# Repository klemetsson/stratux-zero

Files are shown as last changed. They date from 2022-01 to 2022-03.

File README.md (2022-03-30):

# Stratux Zero

Portable ADS-B/Flarm/OGN traffic receiver, AHRS, GNSS, pressure altitude and CO-alarm based on the Stratux project and a Raspberry Pi Zero 2.

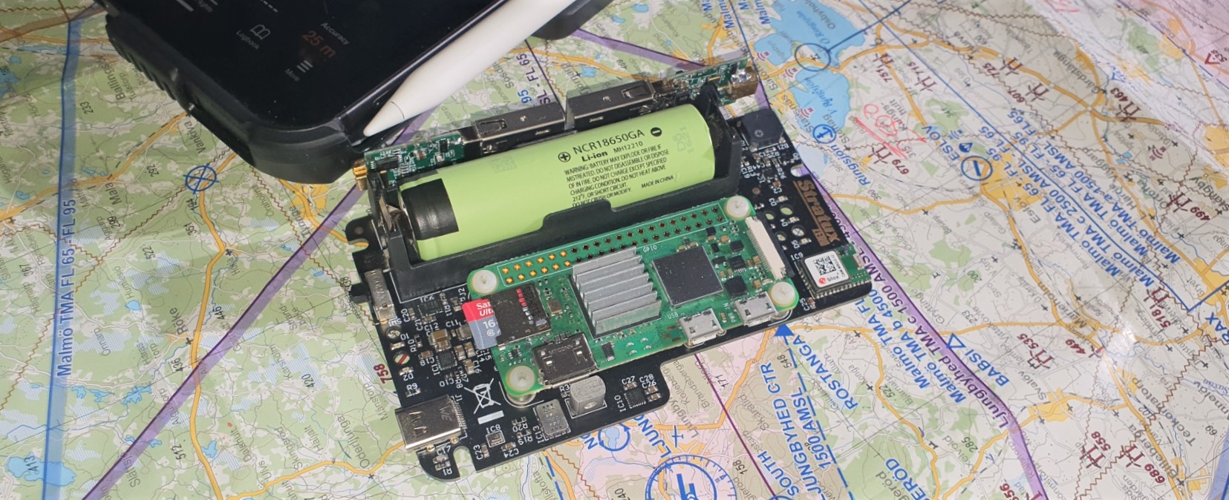
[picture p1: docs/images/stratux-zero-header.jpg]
Stratux Zero


The Flarm/OGN can be reconfigured for 978 MHz UAT for non-European use.

This project is based on the great work of:
- [Stratux (cyoung/stratux)](https://github.com/cyoung/stratux)
- [Stratux - European edition (b3nn0/stratux)](https://github.com/b3nn0/stratux)

The Stratux software for this project is mostly untouched. The main addition is
a more user friendly build system with more configuration and customization
options. It also has the firewall enabled and does more cleanup and tweaking to
enable faster boot time and lower power consumption.

Read more about the Stratux project at [stratux.me](http://stratux.me/) and at [dross:aviation](https://dross.net/aviation/).

> Note that this **does not** replace any primary systems and should only be used as a complement for cross-reference and data collection for post-flight debrief.
> None of the software or hardware has been tested or certified by any independent agent and should not be relied upon.
>
> THE SOFTWARE IS PROVIDED “AS IS”, WITHOUT WARRANTY OF ANY KIND, EXPRESS OR IMPLIED, INCLUDING BUT NOT LIMITED TO THE WARRANTIES OF MERCHANTABILITY, FITNESS FOR A PARTICULAR PURPOSE AND NONINFRINGEMENT.

## Features

- Dual USB 2.0 receptacles for [NooElec NESDR Nano 2+](https://www.nooelec.com/store/nesdr-nano2.html) or similar, [Microchip USB2512](https://www.microchip.com/en-us/product/USB2512)
- Pressure altimeter, [Bosch BMP280](https://www.bosch-sensortec.com/products/environmental-sensors/pressure-sensors/bmp280/)
- 9-axis motion tracking with 3x gyroscopes, 3x accelerometers and 3x compasses, [TDK ICM-20948](https://invensense.tdk.com/products/motion-tracking/9-axis/icm-20948/)
- GNSS (GPS, Galileo, GLONASS, BeiDou) with 2.5 m CEP accuracy, support for GAGAN, WAAS, EGNOS and MSAS augmentation, **does not** support RAIM, [u-blox CAM-M8Q](https://www.u-blox.com/en/product/cam-m8-series)
- GNSS backup power for faster initial lock
- Carbon monoxide detector with 85 dB audible alarm, [SGX MICS-4514](https://sgx.cdistore.com/products/detail/mics4514-sgx-sensortech/333417/)
- Battery socket that take standard 18650 battery without built-in protection
- 4.2 V overvoltage, 2.5 V undervoltage and over-current protection, **make sure to select a battery that is compatible**, [TI BQ2972](https://www.ti.com/product/BQ2972)
- USB C power with built-in 1 A charger (can be set up to 3.15 A with a resistor change), with support for USB BC1.2, USB Type-C Rev. 1.2 CC, Apple, Samsung and legacy USB charge adapters, [Maxim MAX77751](https://www.maximintegrated.com/en/products/power/battery-management/MAX77751.html)
- Can be powered from 4.5 to 13.7 V DC with a connector adapter with a detection resistor
- High and low battery temperature monitoring with charging inhibitor
- Fuel gauge that monitors the battery state of charge and aging, [TI BQ27441](https://www.ti.com/product/BQ27441-G1)
- Hard/soft power switch that first signals the Raspberry to shutdown cleanly and if that takes to long, power will be cut
- Optimized for a Raspberry Pi Zero 2
- Reduced Wifi transmit power to limit the range at which the open access point is visible
- Watchdog that resets the Raspberry Pi if it become unresponsive
- System boots in about 11 seconds
- Five LED indicators
    - Green power indicator that flashes every 5 seconds if low battery and 2 times per second if very low
    - Green Stratux status indicator that flashes when when waiting for startup or loss of GNSS lock
    - Red carbon monoxide alert that flashes every 5 seconds if detected and 2 times per second if CO is high
    - Green external power indicator
    - Orange charge indicator that flashes while charging and turned on when fully charged

The CO-alarm, watchdog, charging temperature monitoring, battery and power management is handled by an [Silicon Labs EFM8BB10 8051 MCU](https://www.silabs.com/mcu/8-bit-microcontrollers/efm8-busy-bee/device.efm8bb10f4g-qfn20).

## TODO

- Testing of first revision PCB and software
- Add fuel gague check in MCU code
- Add default AHRS device orientation settings in Packer build files
- Light pipe CAM files
- Enclosure CAM files

## Contents of this repository

- CAD and CAM files for the custom PCBs
- CAD files for the enclosure
- Source code for the [EFM8 firmware](src/stratux-mcu)
- Source code for the [monitoring](src/gpio-status) and [shutdown](src/gpio-shutdown) service for the Raspberry Pi
- [Hashicorp Packer](https://www.packer.io/) build files and instructions on creating the Raspberry Pi image file

## Design decisions

Because of the global component shortage, many of the components are selected out of availability. This leads to a more expensive design with several difficult component footprints.
Still, several of the components are impossible to acquire separatly and may need to be desoldered from various break-out and development kits.

The integrated 1090 MHz antenna for ADS-B data is a simple dipole design. This however, requires a balun with impedence matching that is located on a separate PCB.

### Power management

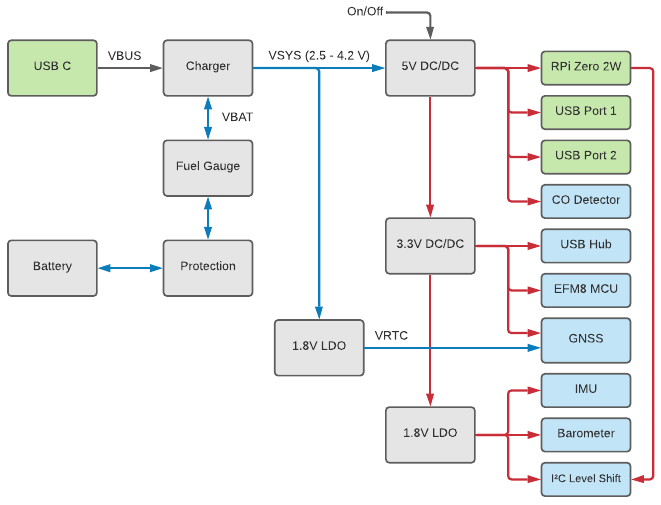
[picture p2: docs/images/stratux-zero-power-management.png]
Power management diagram


There is a DC/DC regulator that take power from the battery or an external USB-C and output the main 5 V supply. This 5 V powers the Raspberry Pi through the GPIO header and powers to the two USB A connectors.

From the 5 V, a 3.3 V and 1.8 V is created to power various circuitry.

The 5 V regulator can be enabled from three sources.

1. The physical power switch will always keep the 5 V active.
2. When external power is provided on the USB-C. However, the EFM8 will keep the Raspberry Pi from starting using the RUN-pin if the physical power switch is in off.
3. The EFM8 can keep the 5 V active to allow the Raspberry Pi to power down cleanly.

An additional 1.8 V is created from the battery to provide a backup power to the u-blox CAM-M8Q. This enable a faster startup and satellite lock.

Multiple test points can be found on the backside of the PCB.

### Ideas for improvements and fixes

- Improve the 5V regulator enable logic so that its weak pull up and leakage current of the EFM8 doesn't cause issues.
- Add a USB power delivery switch to the external ports so that they can.
  be switched off when the unit it charging while Raspberry Pi is not started.
  For example, using two [TI TPS2001D](https://www.ti.com/product/TPS2001D) or a double USB power switch.
- Add a third power switch position that would start the unit whenever there is
  external power. Good for when wanting to start and stop the unit with an external power switch.
  This can be done by implementing a voltage divider that can be sampled by the MCU.
- Add pin header, MOSFET and diode for a 5V fan that can be controlled from GPIO4.
- Switch to a u-blox with RAIM or a dead reckoning GNSS like [NEO-M8U](https://www.u-blox.com/en/product/neo-m8u-module).
- Add battery specifications on the silkscreen visible in the battery holder.
- Move `C3` to batter location between `IN` and `PGND` for `IC2` (MIC2876) to reduce noise from the inductor.
- Add ESD protection for the USB line as the pogo pins make them very exposed.
- Add pull-up resistors to `SHDN`, `PIRDY` and `PISHDN` as the EFM8 only has global internal pull-up enable.
- Thermally isolate the battery temperature sensor so that it isn't cooled by the board. For example by removing the internal planes and moving the ground via.
- Add more test points, for example on the charge disable and SMBus lines.

## Building the Stratux Zero image

These instructions are written for a AMD64 Ubuntu Linux environment and can be run in Windows 10 WSL 2.

### Prerequisites

Install all required components for compiling and building the Raspberry Pi Zero 2 disk image.

Pulling the optional [Drewsif/PiShrink](https://github.com/Drewsif/PiShrink) submodule allows the finished image to be shrunk, making the flashing faster.

**Install required packages:**

```bash
sudo apt-get install git unzip qemu-user-static e2fsprogs dosfstools libarchive-tools jq
```

> There is an issue when running QEMU in WSL on Windows that may require you to run `sudo update-binfmts --enable` after a reboot.
> This could potentially be added to a script in `/etc/profile.d/`.

**Install Packer:**

```bash
curl -fsSL https://apt.releases.hashicorp.com/gpg | sudo apt-key add -
sudo apt-add-repository "deb [arch=amd64] https://apt.releases.hashicorp.com $(lsb_release -cs) main"
sudo apt-get update && sudo apt-get install packer
```

**Install Go if missing:**

```bash
wget -c https://go.dev/dl/go1.17.6.linux-amd64.tar.gz -O - | sudo tar -xz -C /usr/local
export PATH=$PATH:/usr/local/go/bin
echo 'export PATH=$PATH:/usr/local/go/bin' | sudo tee /etc/profile.d/go_path.sh
```

**Build and install packer-builder-arm plugin:**

```bash
git clone https://github.com/mkaczanowski/packer-builder-arm
cd packer-builder-arm
go mod download
go build
sudo mv packer-builder-arm $(dirname $(which packer))
cd ../
rm -Rf packer-builder-arm
```

### Building the image

The build is done using [Hashicorp Packer](https://www.packer.io/) and [a plugin for emulating the ARM architecture using QEMU](https://github.com/mkaczanowski/packer-builder-arm).

```bash
sudo packer build src/stratux-zero-image
```

The build will take around 20 to 45 minutes and will result in a file named `"stratux-zero-raspios-arm64.img"`.
This file can be flashed to an SD card using [Etcher](https://www.balena.io/etcher/) or similar software.

### Customizing

The image can be customized by passing variables to the `packer build` command.

**Build with SSH access enabled:**

```bash
sudo packer build -var enable_ssh=true src/stratux-zero-image
```

> If you plan on enabling SSH, it is a good idea to change the `raspios_username` and `raspios_password` variables.

**Build with developer mode and HDMI output:**

```bash
sudo packer build -var enable_developer_mode=true -var enable_hdmi=true src/stratux-zero-image
```

**Build with SDRs setup for the US:**

```bash
sudo packer build -var enable_uat=true -var enable_ogn=false src/stratux-zero-image
```

The `-var` can be used multiple times and variables can also be passed as JSON or HCL configuration files or as environment variables.

For a full list of variables and their default values, see [variables.pkr.hcl](src/stratux-zero-image/variables.pkr.hcl).

## Building the EFM8 firmware

The onboard 8051 microcontroller requires [Silicon Labs Simplicity Studio](https://www.silabs.com/developers/simplicity-studio) for compiling and flashing the firmware.
The code is written for [Keil Cx51 compiler](https://www.keil.com/support/man/docs/c51/c51_intro.htm) and uses the [Keil RTX51 Tiny](https://www.keil.com/support/man/docs/tr51/tr51_overview.htm) real time operating system. A free Keil license can be registered through Simplicity Studio.

### Silicon Labs debug cable adapter

To program the board you will need a [Silicon Labs USB Debug Adapter](https://www.silabs.com/development-tools/mcu/8-bit/8-bit-usb-debug-adapter) and a [TC2030-IDC 6-pin Tag-Connect cable](https://www.tag-connect.com/product/tc2030-idc-6-pin-tag-connect-plug-of-nails-spring-pin-cable-with-legs).
Four pins need to be wired between the debug adapter and the Tag-Connect cable.

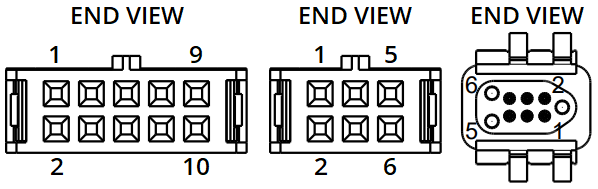
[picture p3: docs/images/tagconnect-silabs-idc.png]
Silicon Labs Debug Adapter and TC2030 IDC pinout


| Description | Debug Adapter IDC Pin # | TC IDC Pin # | TC TAG Pin # |
|---|---|---|---|
| Not Connected | 1 | | |
| GND (Ground) | 2 | | |
| GND (Ground) | 3 | | |
| **C2D** | **4** | **3** | **3** |
| C2CK pin share | 5 | | |
| **C2D pin share**  | **6** | **5** | **5** |
| **C2CK** | **7** | **2** | **2** |
| Not Connected | 8 | | |
| **GND (Ground)** | **9** | **4** | **4** |
| USB Power | 10 | | |

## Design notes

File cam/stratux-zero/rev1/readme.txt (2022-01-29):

PCB Fabrication Notes:

1) 4 layer 1.6mm FR-4 with JLCPCB stackup and JLC7628
2) ENIG
3) Black or green solder mask
4) J1 holes may be adjusted as long as 0.18 mm pins fit
5) Solder mask should cover bottom layer pads of MP1 and header for J2 as per the file
6) The 4 pads under J2 should also have the pads covered with solder mask on bottom layer as per the file
7) Stencil shall have openings for the header of J2 and the 4 pads under J2
8) Stencil shall have openings for the J1 pin holes

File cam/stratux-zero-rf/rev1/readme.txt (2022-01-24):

PCB Fabrication Notes:

1) 2 layer 0.8mm FR-4 with JLCPCB stackup
2) HASL or ENIG
3) Green or black solder mask

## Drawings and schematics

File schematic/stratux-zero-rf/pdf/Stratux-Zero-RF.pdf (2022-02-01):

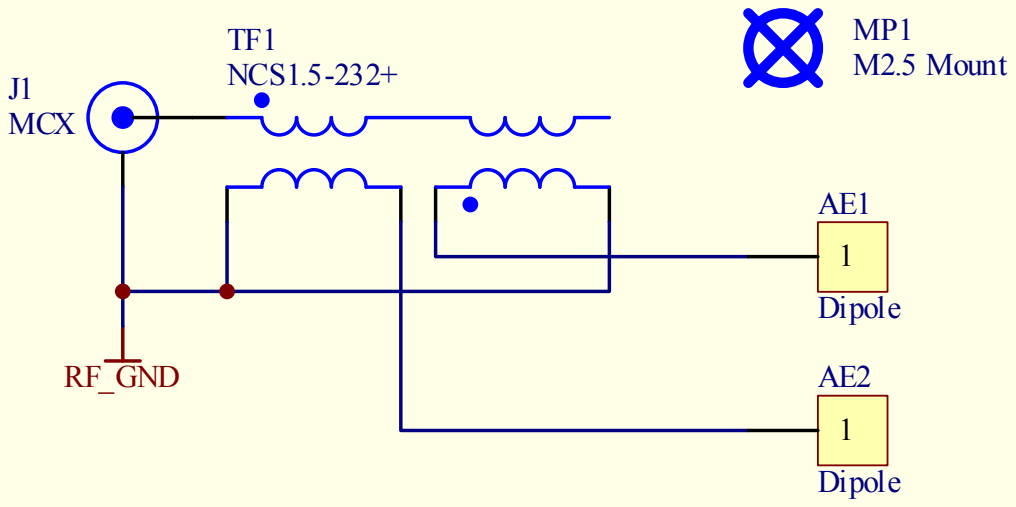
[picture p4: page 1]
J1MCX; RF_GND; TF1 NCS1.5-232+

1 AE1 Dipole 1 AE2 Dipole MP1 M2.5 Mount

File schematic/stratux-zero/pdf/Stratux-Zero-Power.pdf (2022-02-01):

# IC2 MIC2876-AYMT-T5 C1

910k R3

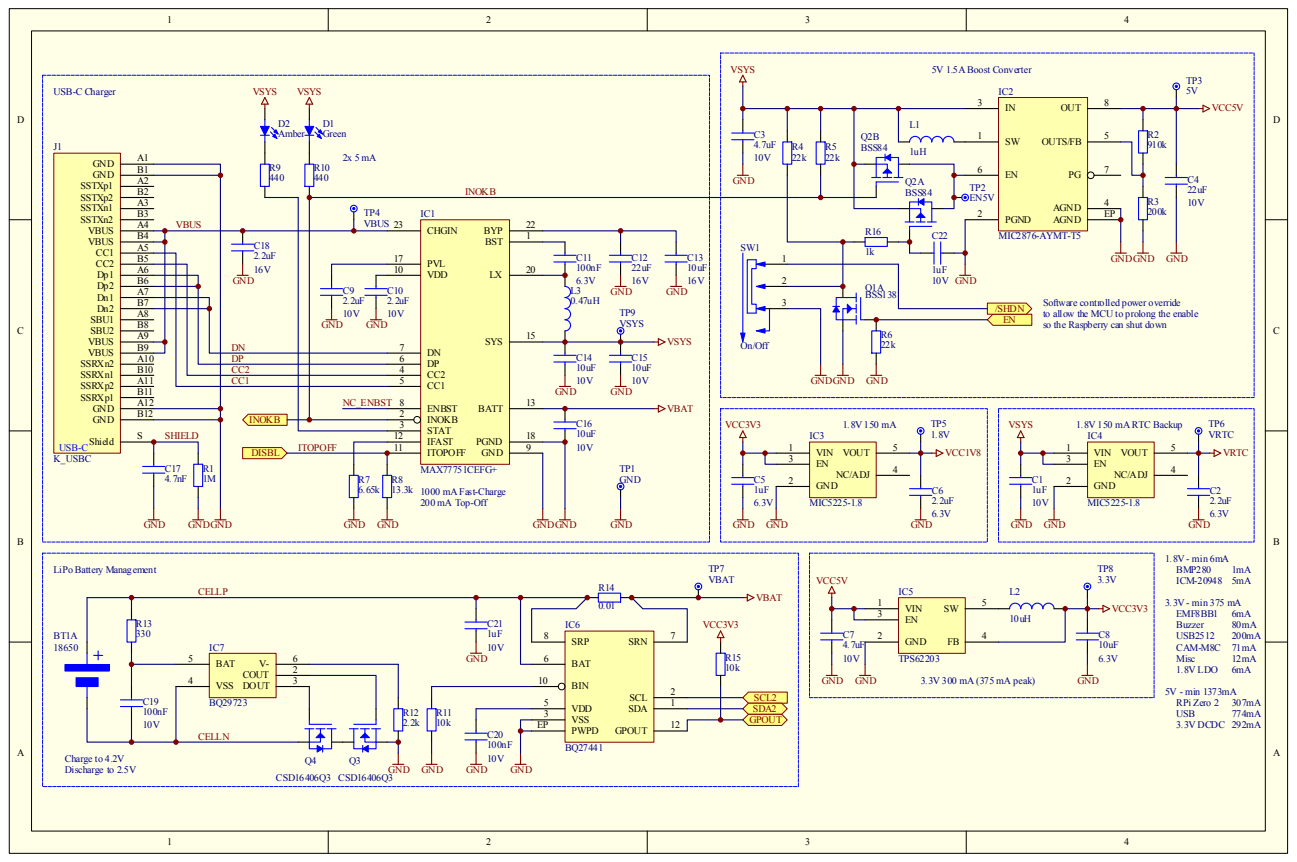
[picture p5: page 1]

to allow the MCU to prolong the enable

CELLP LiPo Battery Management C19

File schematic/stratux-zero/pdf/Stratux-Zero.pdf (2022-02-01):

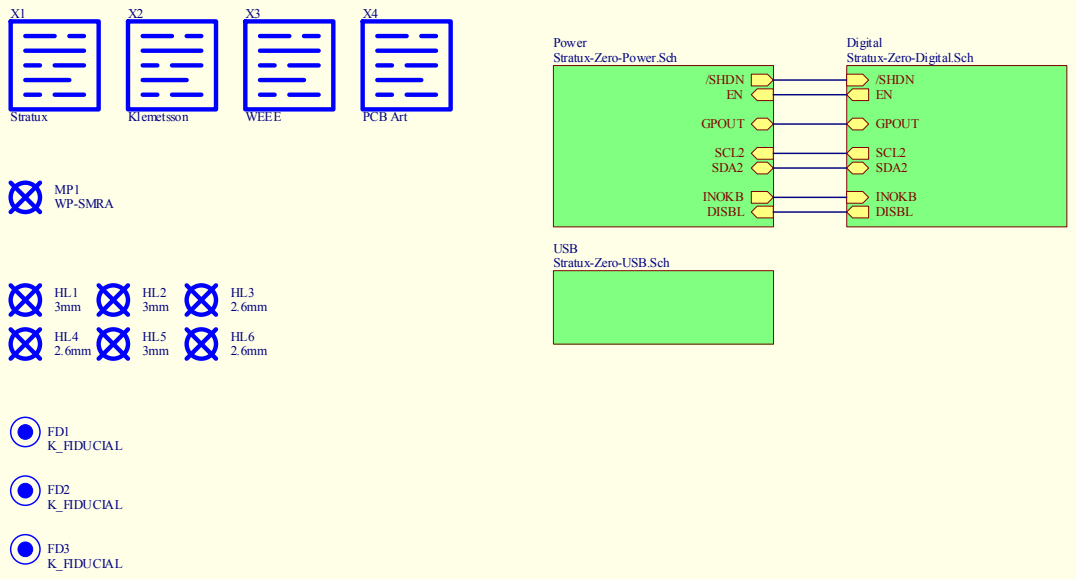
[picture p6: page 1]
/SHDN; SCL2 SDA2 GPOUT; INOKB DISBL; Power Stratux-Zero-Power.Sch; FD2 K_FIDUCIAL; FD3 K_FIDUCIAL; 3mm MP1 WP-SMRA; X1 Stratux; X2 Klemetsson; X3 WEEE; X4 PCB Art

Stratux-Zero-Digital.Sch USB

INOKB DISBL Digital

Stratux-Zero-USB.Sch FD1 K_FIDUCIAL

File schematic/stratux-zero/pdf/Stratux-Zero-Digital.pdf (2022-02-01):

# 260D5 Red VCC3V3

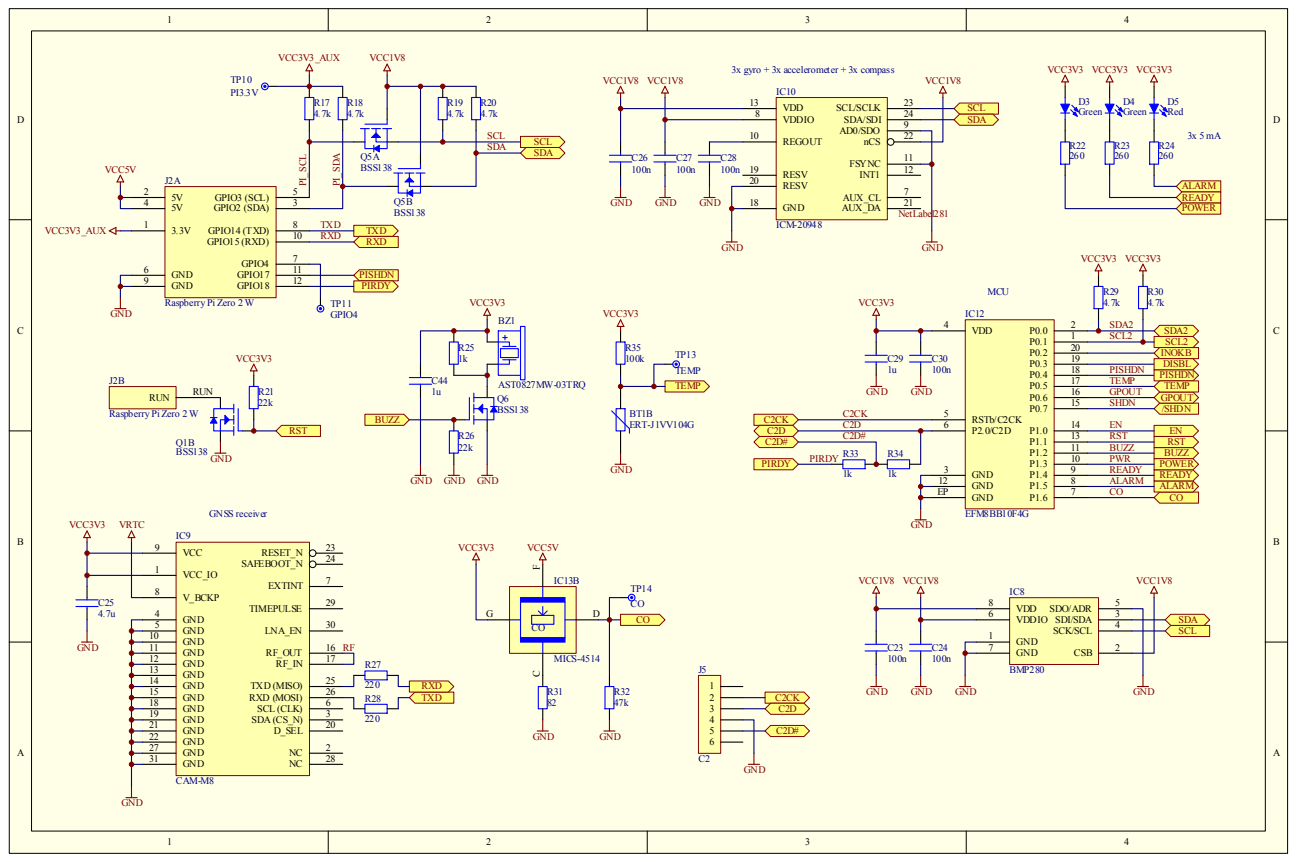
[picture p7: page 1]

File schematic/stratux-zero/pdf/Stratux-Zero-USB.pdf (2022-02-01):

# VCC3V3 C33

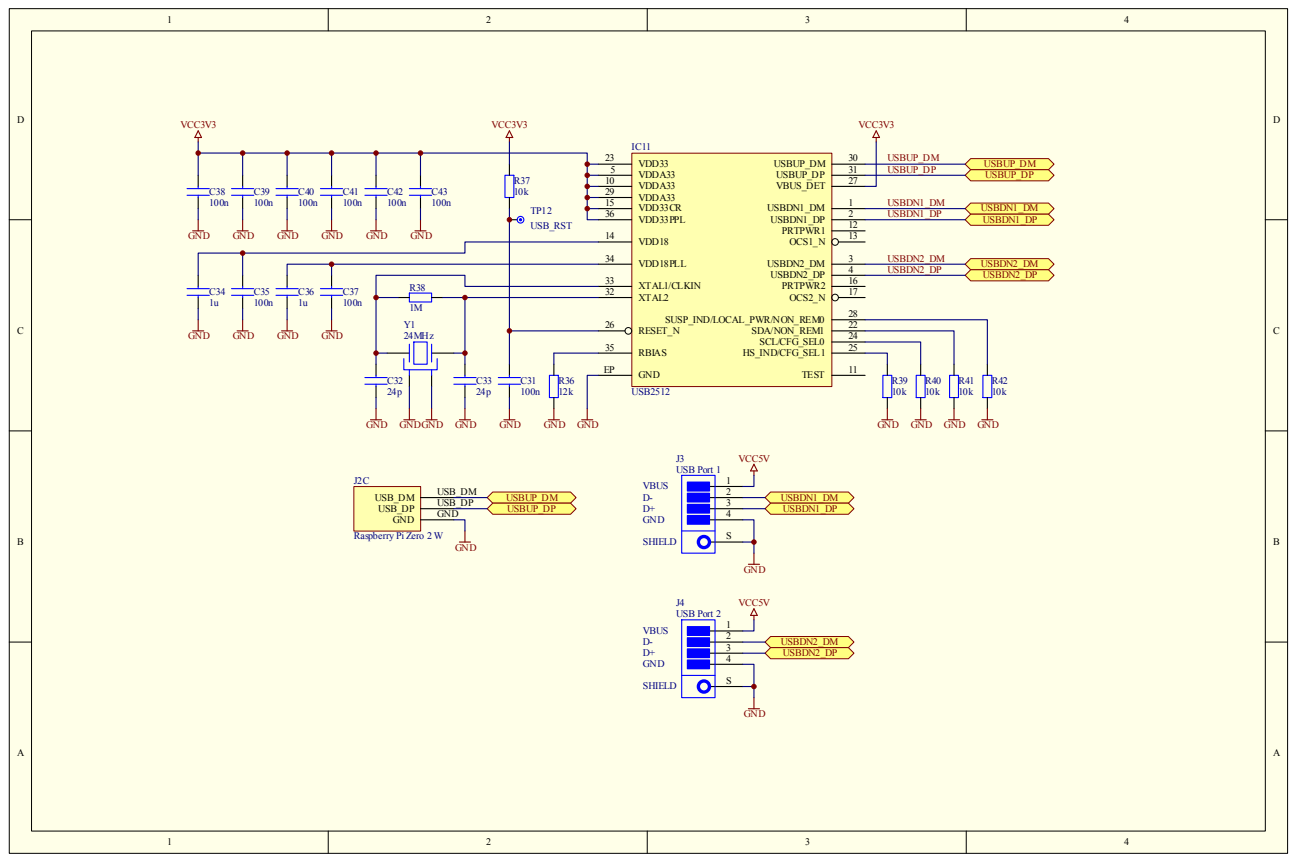
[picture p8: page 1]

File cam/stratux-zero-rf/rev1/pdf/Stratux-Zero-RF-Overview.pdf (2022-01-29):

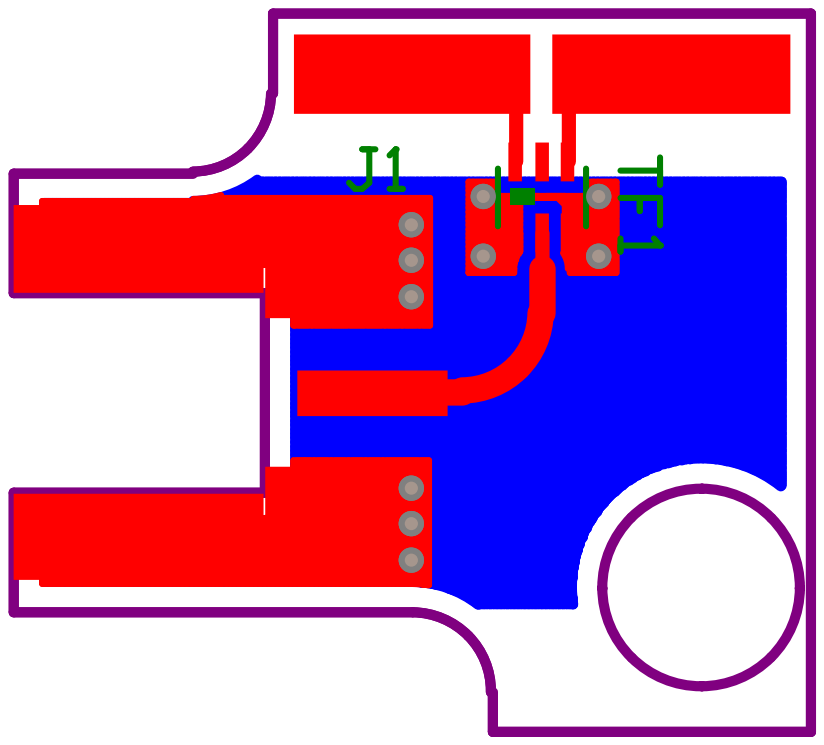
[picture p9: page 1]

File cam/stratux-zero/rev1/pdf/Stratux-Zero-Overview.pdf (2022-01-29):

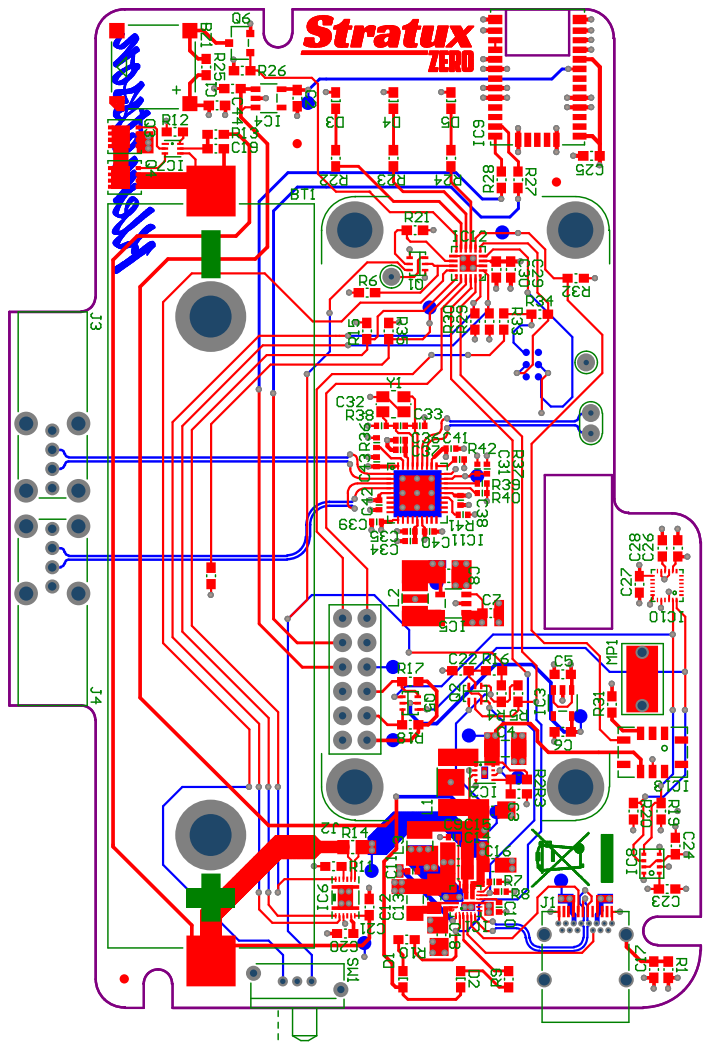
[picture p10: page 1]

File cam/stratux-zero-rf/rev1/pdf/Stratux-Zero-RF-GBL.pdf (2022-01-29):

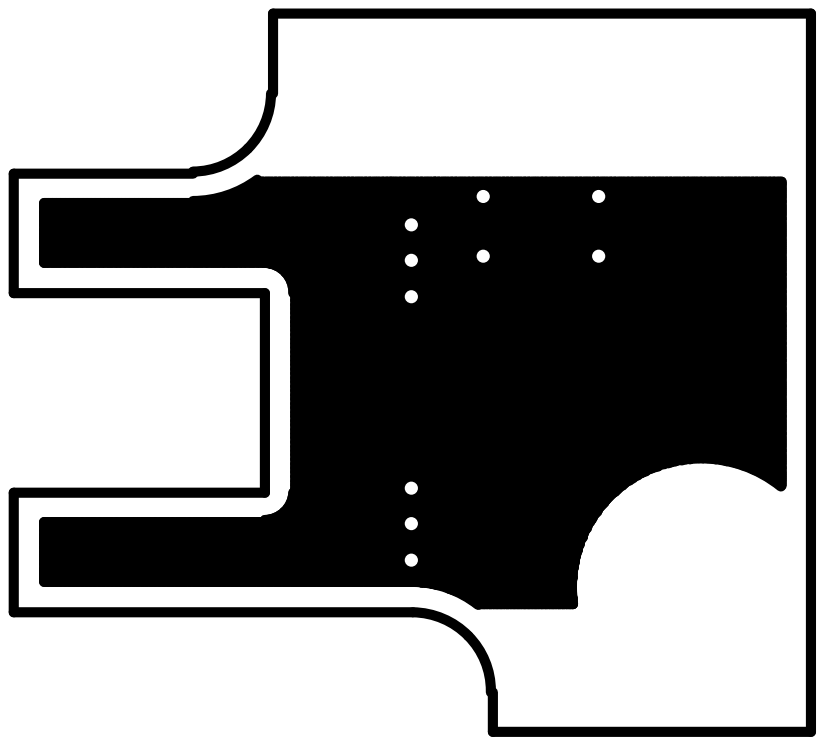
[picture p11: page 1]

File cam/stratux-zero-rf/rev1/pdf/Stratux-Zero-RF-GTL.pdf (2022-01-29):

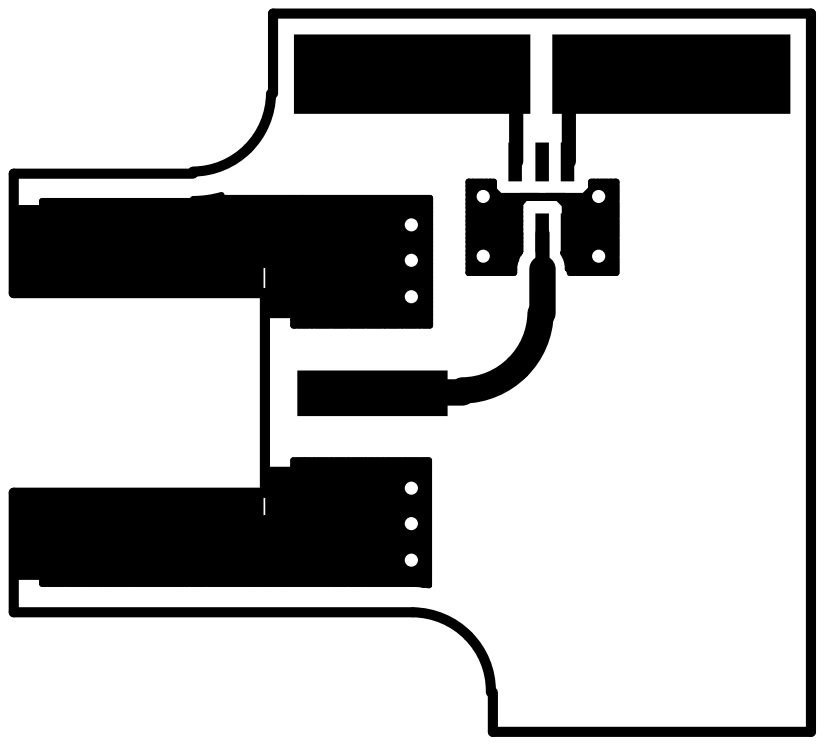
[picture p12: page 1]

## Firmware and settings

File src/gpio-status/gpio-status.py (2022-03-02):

#!/usr/bin/env python3
"""
Monitor the status of the Stratux service and signal this on a GPIO pin.

While the status is OK, the pin will pulse every 1 second. This allow
the external monitor to reset in case the service is not running.
For example because of a kernal panic.

If GNSS is enabled but not enough satellites, then the pulse will be
200 ms, otherwise 500 ms.
"""

import os
import sys
import time
import signal
import logging
import requests
import RPi.GPIO as GPIO


STRATUX_STATUS_URL = 'http://127.0.0.1/getStatus'
STRATUX_SETTINGS_URL = 'http://127.0.0.1/getSettings'

MIN_SATELLITES = 3


def _main(gpio):
    """Monitor the status of Stratux."""

    logging.info('Monitoring Stratux and signaling on GPIO pin {0}'.format(gpio))

    # Setup the status GPIO pin
    GPIO.setwarnings(False)
    GPIO.setmode(GPIO.BCM)
    GPIO.setup(gpio, GPIO.OUT)
    GPIO.output(gpio, GPIO.LOW)

    # Loop until shutting down
    signal.signal(signal.SIGINT, lambda _s, _f: sys.exit(0))
    while True:
        # Check if GPS is enabled
        try:
            response = requests.get(STRATUX_SETTINGS_URL, timeout=1)
            response.raise_for_status()
            data = response.json()
        except requests.RequestException:
            has_gnss = False
        else:
            has_gnss = 'GPS_Enabled' in data and data['GPS_Enabled']

        # Check status
        try:
            response = requests.get(STRATUX_STATUS_URL, timeout=2)
            response.raise_for_status()
            data = response.json()
        except requests.RequestException:
            GPIO.output(gpio, GPIO.LOW)
            time.sleep(1)
        else:
            if 'GPS_connected' in data and data['GPS_connected']:
                has_gnss_lock = 'GPS_satellites_locked' in data and data['GPS_satellites_locked'] >= MIN_SATELLITES
            else:
                has_gnss_lock = False
            # Send a pulse if Stratux is available
            if has_gnss and not has_gnss_lock:
                # Shorter pulse if alive, but waiting for GNSS
                GPIO.output(gpio, GPIO.HIGH)
                time.sleep(0.2)
                GPIO.output(gpio, GPIO.LOW)
                time.sleep(0.8)
            else:
                GPIO.output(gpio, GPIO.HIGH)
                time.sleep(0.5)
                GPIO.output(gpio, GPIO.LOW)
                time.sleep(0.5)


if __name__ == "__main__":
    _main(int(sys.argv[1]))

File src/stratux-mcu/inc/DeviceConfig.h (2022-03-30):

/*
 * DeviceConfig.h
 *
 *  Created on: 28 feb. 2022
 *      Author: Christian Klemetsson
 */

#ifndef INC_DEVICECONFIG_H_
#define INC_DEVICECONFIG_H_

//-----------------------------------------------------------------------------
// Macros
//-----------------------------------------------------------------------------

// Convert reference resistance values to ADC raw values based of the ERTJ1VV104
// ADC is 10-bit, 0.5x gain and uses 1.65V reference
#define TEMP_RES_2_ADC(res) ((uint16_t)((1023 * res) / (1 + res)))

// SMBus helpers
#define smbus_write_command(cmd) { \
  smbus_busy = true; \
  smbus_error = false; \
  smbus_read = false; \
  smbus_cmd = cmd; \
  SMB0CN0_STA = true; \
}
#define smbus_read16() { \
  smbus_busy = true; \
  smbus_error = false; \
  smbus_read = true; \
  SMB0CN0_STA = true; \
}

// Make the buzzer buzz
#define start_buzzer() {TMR2CN0 |= TMR2CN0_TR2__RUN; }
#define stop_buzzer() {TMR2CN0 &= ~TMR2CN0_TR2__RUN; O_BUZZER = false;}

// Enable charging
#define charge_enable() {P0MDIN &= ~P0MDIN_B3__DIGITAL;}

// Disable charging
#define charge_disable() {P0MDIN |= P0MDIN_B3__DIGITAL; O_DISBL = false;}

// Get the INOKB status
#define has_ext_pwr() (CMP0CN0 & CMP0CN0_CPOUT__POS_GREATER_THAN_NEG)

// Make a beep with the buzzer in ms
#define beep(delay) {start_buzzer(); os_wait2(K_TMO, delay); stop_buzzer();}

//-----------------------------------------------------------------------------
// Constants
//-----------------------------------------------------------------------------

// Task IDs for RTX51 Tiny
#define TASK_ID_MAIN       0 // Main task that manages the current state
#define TASK_ID_INDICATORS 1 // Task to manage LEDs and the buzzer
#define TASK_ID_SENSORS    2 // Read temperature, CO level and state of charge

// Bits that need to be cleared for the watchdog to refresh
#define WATCHDOG_MASK_INDICATORS (1)
#define WATCHDOG_MASK_SENSORS    (2)
#define WATCHDOG_MASK_TIMER      (4)
#define WATCHDOG_MASK            (WATCHDOG_MASK_INDICATORS | WATCHDOG_MASK_SENSORS | WATCHDOG_MASK_TIMER)

// Calculated levels for battery temperature
#define BAT_TEMP_LOW_ON   TEMP_RES_2_ADC(3.0150) // Disable charging under +5 degree C
#define BAT_TEMP_LOW_OFF  TEMP_RES_2_ADC(2.6385) // Enable charging over +7.5 degree C
#define BAT_TEMP_HIGH_ON  TEMP_RES_2_ADC(0.3723) // Disable charging over +45 degree C
#define BAT_TEMP_HIGH_OFF TEMP_RES_2_ADC(0.4721) // Enable charging under +40 degree C

// Battery charge states
#define BAT_CHARGE_UNKNOWN  (0) // Unknown charge
#define BAT_CHARGE_OK       (1) // Battery charge is okay
#define BAT_CHARGE_WARNING  (2) // You should charge
#define BAT_CHARGE_CRITICAL (3) // Will shutdown soon
#define BAT_CHARGE_EMPTY    (4) // Shutting down
#define BAT_CHARGE_ERROR    (5) // Could not get battery charge

// Battery state of charge thresholds in %
#define BAT_SOC_WARNING  (20) // Level to trigger BAT_CHARGE_WARNING
#define BAT_SOC_CRITICAL (5)  // Level to trigger BAT_CHARGE_CRITICAL
#define BAT_SOC_EMPTY    (2)  // Level to trigger BAT_CHARGE_EMPTY

// Carbonmonoxide states
#define CO_LEVEL_UNKNOWN  (0) // Unknown CO level
#define CO_LEVEL_OK       (1) // No dangerous levels
#define CO_LEVEL_WARNING  (2) // Symptoms may appear (> 50 ppm)
#define CO_LEVEL_CRITICAL (3) // Headaches and fatigue (> 125 ppm)
#define CO_LEVEL_LETHAL   (4) // Life threatening in hours (> 400 ppm)

// Calculated using /tools/mics4515-ref
#define CO_ADC_WARNING  (0x038c)
#define CO_ADC_CRITICAL (0x03c7)
#define CO_ADC_LETHAL   (0x03ea)

// States for the Stratux software running on the Raspberry
// These are detected using pulse length on a GPIO status pin
#define STRATUX_UNKNOWN (0) // Unknown state of the Stratux
#define STRATUX_RUNNING (1) // Stratux is started
#define STRATUX_READY   (2) // Stratux is started and is ready
#define STRATUX_TIMEOUT (3) // Stratux heartbeat has timed out

// I2C fuel gauge constants
#define BQ72441_I2C_ADDRESS (0x55 << 1)
//#define BQ27441_COMMAND_SOC (0x1c) // StateOfCharge()
#define BQ27441_COMMAND_SOC (0x04)

// SMBus constants
#define SMB0CN0_MTSTA (0xe0) // (MT) start transmitted
#define SMB0CN0_MTDB  (0xc0) // (MT) data byte transmitted
#define SMB0CN0_MRDB  (0x80) // (MT) data byte received

//-----------------------------------------------------------------------------
// Stratux state machine states
//-----------------------------------------------------------------------------

// Initial state
// Read current battery level
// -> STATE_SHUTDOWN if battery ok
// -> STATE_POWEROFF if battery not ok
#define STATE_BOOT (0)

// Start the Stratux
// Toggle RUN/RESET
// -> STATE_STARTING
#define STATE_START (1)
#define STATE_START_GRACE (2)

// Stratux starting up
// Read I_PIRDY
// -> STATE_RUNNING if I_PIRDY goes low
// -> STATE_START if timeout (28s)
#define STATE_STARTING (3)

// Boot has timed out
// -> STATE_START
#define STATE_START_TIMEOUT (4)
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

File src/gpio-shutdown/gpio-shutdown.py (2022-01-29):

#!/usr/bin/env python3
"""A service that listens to a GPIO and triggers a shutdown on falling flank."""

import os
import sys
import time
import signal
import logging
import RPi.GPIO as GPIO


def _main(gpio):
    """Setup the GPIO watcher."""

    logging.info('Listening on GPIO pin {0} for shutdown'.format(gpio))

    # Setup the shutdown GPIO pin
    GPIO.setwarnings(False)
    GPIO.setmode(GPIO.BCM)
    GPIO.setup(gpio, GPIO.IN, pull_up_down=GPIO.PUD_UP)
    GPIO.add_event_detect(
        gpio, GPIO.FALLING,
        callback=lambda _e: os.system('shutdown -h now'),
        bouncetime=100
    )

    # Loop until shutting down
    signal.signal(signal.SIGINT, lambda _s, _f: sys.exit(0))
    while True:
        time.sleep(10)


if __name__ == "__main__":
    _main(int(sys.argv[1]))

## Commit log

2022-01-24 feat: Add packer build file for creating the RPi disk image
    [config.txt]
2022-01-26 feat: Use Packer HCL template for building disk image
    [config.txt]
2022-01-27 docs: Description of power management
2022-01-28 feat: Allow Wifi power to be set
2022-01-28 docs: Mention non-eu support, max charge current and boot time
2022-01-29 chore: Bump Raspberry Pi OS base image
2022-01-29 feat: Render the `interfaces.template` so that Wifi power and netmask persist
2022-01-29 style: Disable audio, camera and display detect
2022-01-29 fix: Add missing argument
    [gpio-shutdown.py]
2022-01-29 style: Add the latest rev1 PCB CAM files
    [Stratux-Zero-RF.GBL, Stratux-Zero-RF.GBO, Stratux-Zero-RF.GBS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]
2022-01-29 docs: Add power management diagram
2022-01-29 docs: Add more labels to power diagram
2022-01-30 docs: Add I2C level shifter
2022-02-01 feat: Add schematic and PCB files
    [Stratux-Zero-Digital.Sch, Stratux-Zero-Power.Sch, Stratux-Zero-RF.Sch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]
2022-03-02 feat: Signal waiting for GNSS on the status GPIO pin
2022-03-30 feat: Impove Stratux state machine and sensor reading
2022-03-30 docs: Needed fix for the 5V regulator enable logic
